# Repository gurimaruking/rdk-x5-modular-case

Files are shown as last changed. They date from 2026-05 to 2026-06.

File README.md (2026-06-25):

# RDK X5 Modular Case

> **The first open-source 3D-printable case for D-Robotics RDK X5 8GB.**
> Fully parametric OpenSCAD source. One base, four swappable lids.
> Licensed under **CC BY 4.0**.

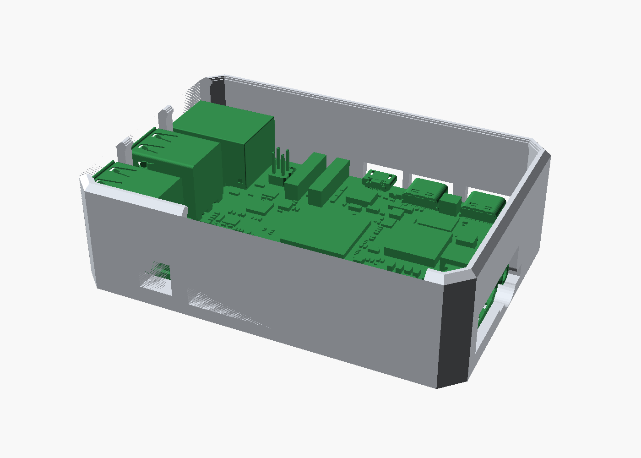
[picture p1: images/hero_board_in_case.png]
RDK X5 seated in the base — every port lined up


<p align="center">
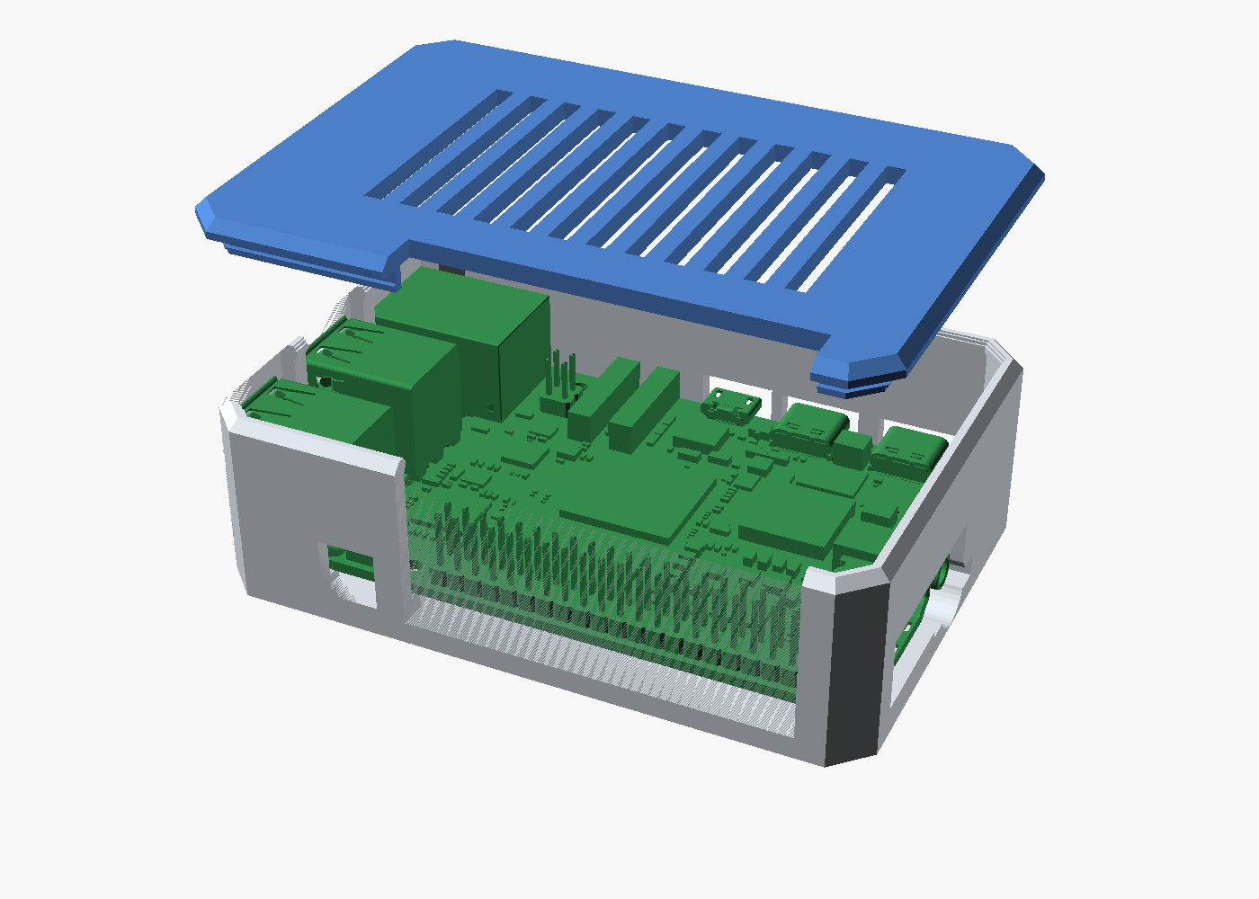
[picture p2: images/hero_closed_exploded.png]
Closed lid snapping on
  
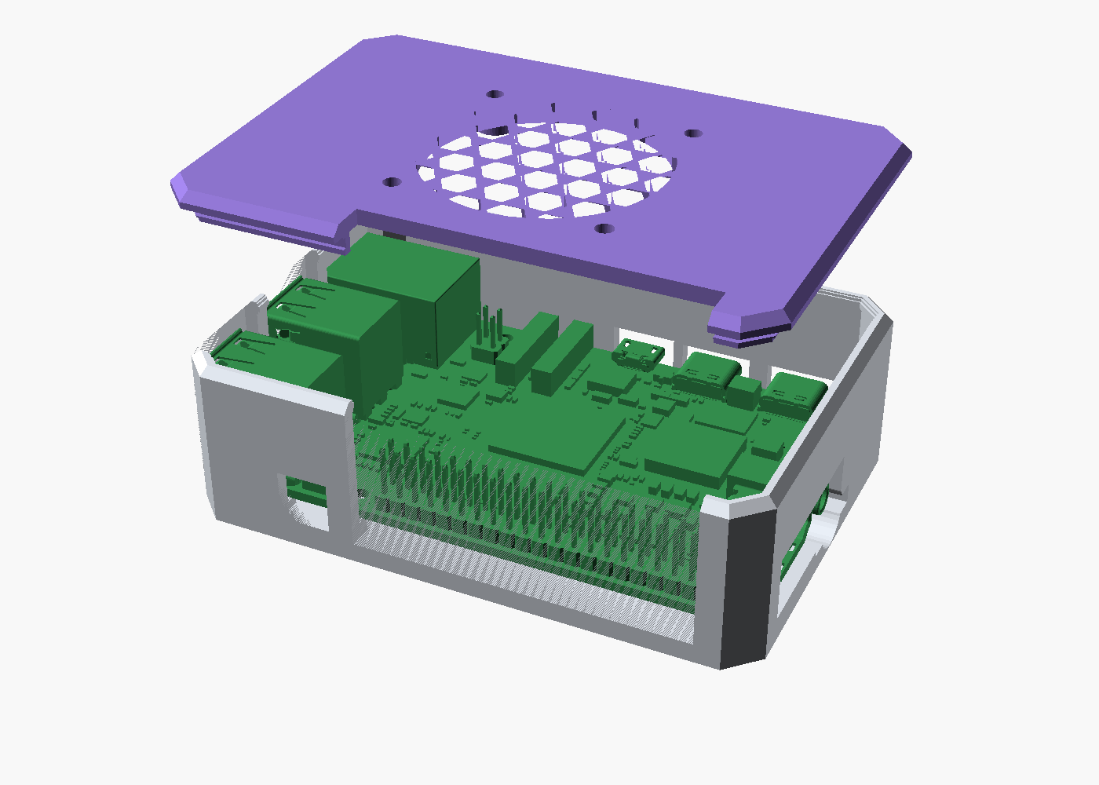
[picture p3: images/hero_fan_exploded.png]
Fan lid snapping on
  
</p>

> Snap-on lids over a board held by an outer clamp — no PCB-side screws.

## Why this exists

As of May 2026, RDK X5 has **no community 3D-printable case** on Printables,
Thingiverse, Cults3D, or English-language MakerWorld. The official metal/acrylic
cases from Yahboom, Waveshare, and DFRobot are heavy and don't fit inside
robot bodies. This repo fills that gap with a community-first, remix-friendly
modular design.

Originally built as a byproduct of [Project Korosuke (コロ助)](https://github.com/Robostadion/corosuke-robot),
an animatronic robot competing in the **D-Robotics Robotics Dream Keeper Challenge**.

## One base, four lids

| Lid | Preview | STL | Use case |
|-----|---|-----|---|
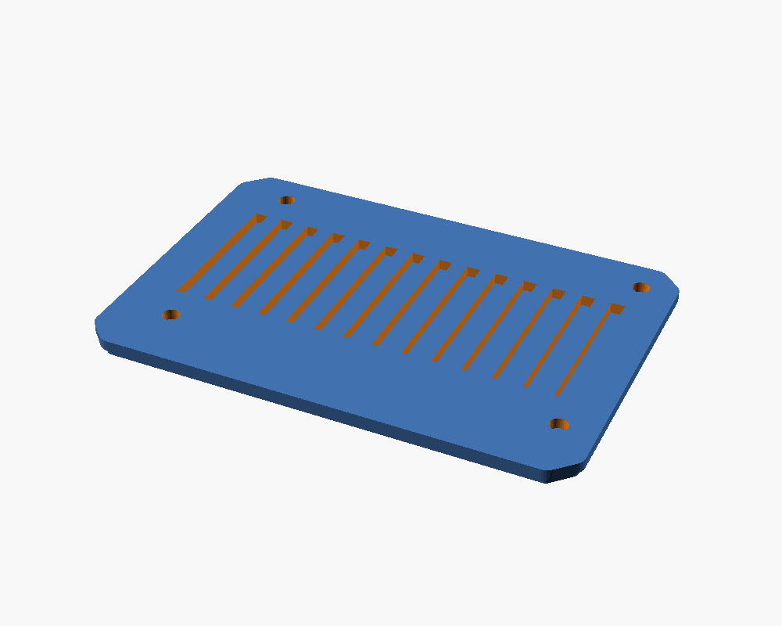
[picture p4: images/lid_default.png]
| **Default** (closed, cooling slits) |  | [`lid_default.stl`](stl/lid_default.stl) | Everyday use, dust protection, mild cooling |
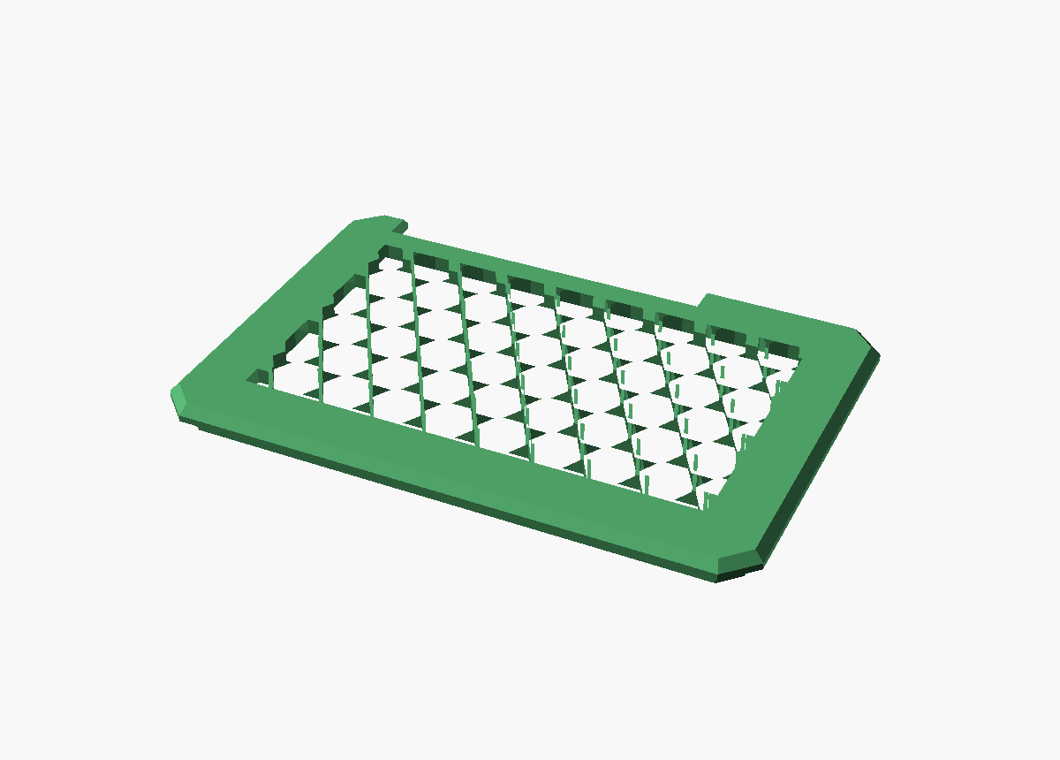
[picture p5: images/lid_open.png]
| **Open** (honeycomb vent) |  | [`lid_open.stl`](stl/lid_open.stl) | Maker projects, full heatsink exposure, max airflow |
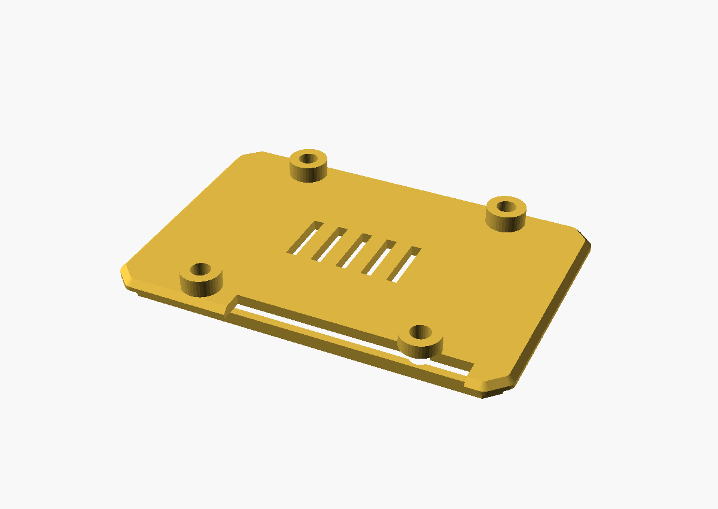
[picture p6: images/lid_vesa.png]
| **VESA Mount** (50×50 M4) |  | [`lid_vesa.stl`](stl/lid_vesa.stl) | 50 mm 4-hole bracket mount (board is too small for full VESA-75) |
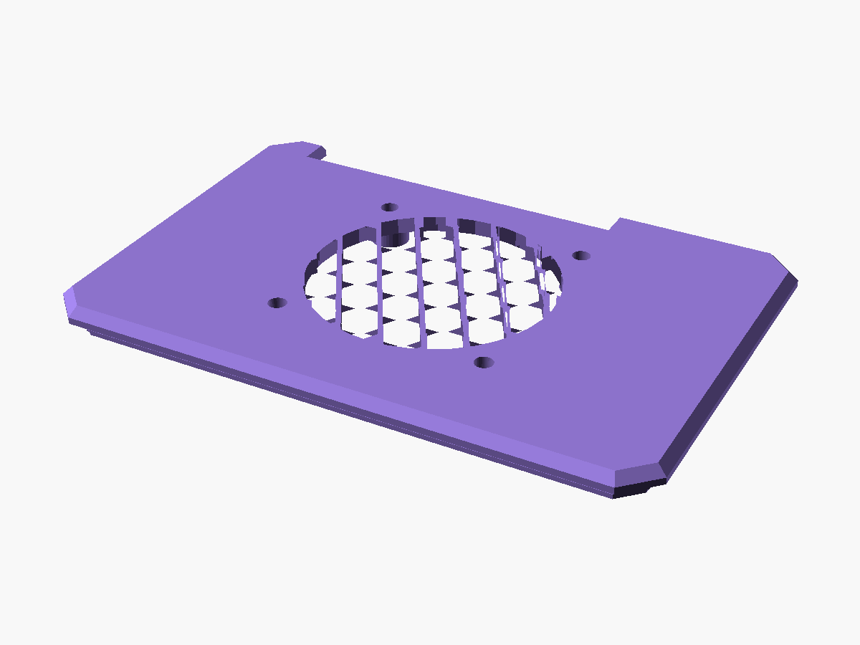
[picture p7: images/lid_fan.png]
| **Fan** (40 mm fan mount) |  | [`lid_fan.stl`](stl/lid_fan.stl) | Active cooling — mount a 40 mm fan (e.g. 4010) over a honeycomb intake grille |

Common base: [`case_base.stl`](stl/case_base.stl) — works with all four lids.

### Powering the fan

The **Fan lid** takes a standard **40 × 40 × 10 mm (4010) 5 V fan**, held by
**4× M3 × 15 mm screws** on the 32 mm pattern — that length is a perfect fit
through the fan into the lid bosses. The center honeycomb doubles as a finger
guard and intake grille; the fan blows down onto the heatsink.

> ⚠️ The RDK X5's onboard fan header (**J15**) is a JST-SH **1.0 mm 2-pin** and
> is too small for most hobby-fan plugs. The simplest reliable hookup is the
> **40-pin GPIO header**: fan **+ (red) → pin 4 (5V)**, **− (black) → pin 6 (GND)**.
> This runs the fan full-speed whenever the board is powered.
>
> **Measured cooling (assembled, lid on):** idle **66 °C passive → 41 °C** with the
> 4010 fan ducted through the honeycomb — a **−25 °C** drop, plenty of headroom for
> running YOLO on the BPU.

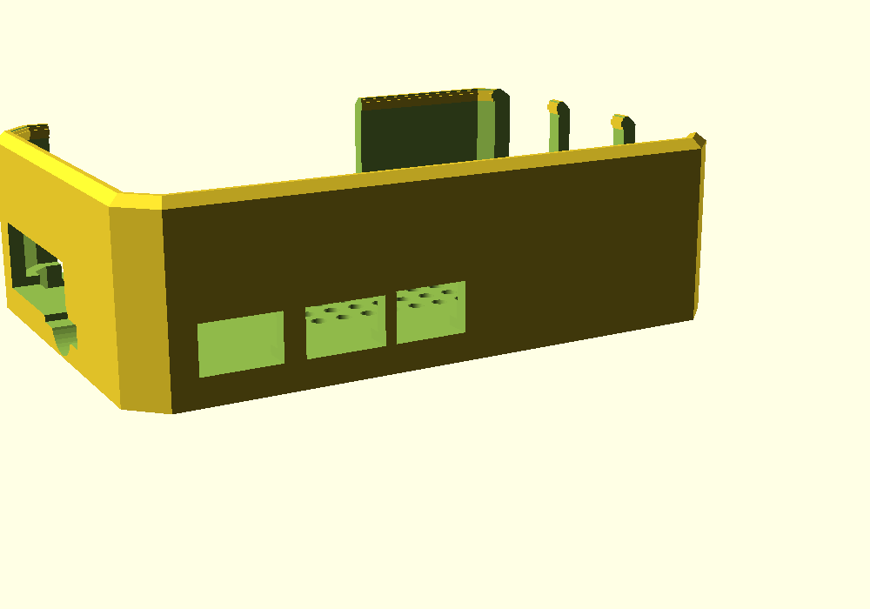
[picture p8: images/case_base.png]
Base


## Specifications

| Item | Value |
|---|---|
| Compatible board | D-Robotics RDK X5 8GB (Part No. DROBOTICS-RDK-X5-8GB-V10) |
| Reference source | Official D-Robotics V1P0 DXF & STEP (`reference/`) |
| Case footprint | ~89 × 60 × 24 mm |
| PCB retention | Outer clamp (no PCB-side screws — preserves stock heatsink holes) |
| Lid attachment | **Snap / press-fit — no screws** (tunable via `SNAP_CLEAR`) |
| Designed material | PLA / PETG (2.0 mm wall) |
| License | CC BY 4.0 |

## Build (STL from source)

Requires [OpenSCAD](https://openscad.org/) 2021.01 or newer.

```bash
# Render all parts in one go
openscad -o stl/case_base.stl   -D 'SHOW=11' rdk_x5_case.scad
openscad -o stl/lid_default.stl -D 'SHOW=12' rdk_x5_case.scad
openscad -o stl/lid_open.stl    -D 'SHOW=13' rdk_x5_case.scad
openscad -o stl/lid_vesa.stl    -D 'SHOW=14' rdk_x5_case.scad
openscad -o stl/lid_fan.stl     -D 'SHOW=25' rdk_x5_case.scad
# (SHOW=11–14,25 = print-ready, flat on Z=0. SHOW=1–4,15 = design orientation.)
```

Or run `./build_all.sh` (Linux/macOS) / `build_all.ps1` (Windows).

## Print settings (suggested starting point)

| Parameter | Value |
|---|---|
| Layer height | 0.20 mm |
| Walls / Perimeters | 3 |
| Top/Bottom layers | 4 / 4 |
| Infill | 20 % (gyroid) |
| Supports | **None needed** — designed support-free |
| Brim | Optional (5 mm) for warping-prone filaments |
| Filament | PLA, PETG, or PC-blend; ABS optional |

## Customization

Open `rdk_x5_case.scad` and edit the `// PARAMETERS` block. Useful knobs:

| Variable | Default | When to change |
|---|---|---|
| `GAP` | 1.0 mm | Per-side PCB clearance. Lower (0.8) for a snug board, raise if it binds. Printers with elephant's foot may need more — or enable foot compensation in the slicer |
| `SNAP_CLEAR` | 0.05 mm | Lid lip press-fit. Lower = tighter lid; negative = interference |
| `SNAP_BEAD` | 0.45 mm | Snap ridge/groove engagement depth. Raise for a firmer click, lower if the lid won't close |
| `TOP_CLEAR` | 20 mm | Increase if using a tall heatsink + fan |
| `WALL` | 2.2 mm | Drop to 1.6 for ABS, raise to 3.0 for TPU |
| `VESA` | 50 (50×50 M4) | Max that fits on the 56 mm-deep lid; an assert guards against overhang |

## Roadmap

- [x] Default Lid — closed + cooling slits
- [x] Open Lid — frame with X-cross ribs
- [x] VESA Mount Lid — 50×50 M4 pattern (bosses fully supported on the lid)
- [x] Fan Lid — 40 mm fan mount (32 mm M3 pattern) with honeycomb intake grille
- [x] Accurate port cutouts — every connector position extracted from the
      official STEP model and verified against the real board mesh
      (USB-A ×2, RJ45, HDMI, audio, USB-C ×2, UART debug, 40-pin GPIO, microSD, fan).
      See [connector_map.md](connector_map.md) and
      `images/board_fit_verification.png`.
- [ ] Camera Lid — MIPI CSI cable pass-through (planned)
- [ ] DIN-rail Lid — industrial mount (community request welcome)
- [ ] Print validation on real hardware (PLA / PETG)
- [ ] Thermal validation under load

## Disclaimer

This is an unofficial community design. Not affiliated with or endorsed by
D-Robotics. PCB outline geometry is derived from D-Robotics' publicly
released DXF/STEP mechanical drawings (`reference/`); those original CAD
files remain the property of D-Robotics and are included for design
verification only.

## License

**CC BY 4.0** — see [LICENSE](LICENSE). You may share and adapt freely,
including commercially, as long as you give credit.

## Acknowledgments

- **D-Robotics** for publishing the mechanical reference files openly.
- **Lisa Li** and the Robotics Dream Keeper Challenge team for the warm welcome.
- The Korosuke / コロ助 character from *Kiteretsu Daihyakka* — the spark
  for this entire project.

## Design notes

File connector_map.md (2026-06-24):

# RDK X5 コネクタ実測マップ(公式STEPから抽出)

> 抽出元: RDK_X5_LPDDR4_4266MHz_V1P0_pcb.stp(FreeCADでbbox抽出)
> 座標系: 基板左下を原点、X 0..85 / Y 0..56 mm(DXF外形と一致)
> Z: 基板上面を概ね0として、コネクタの高さ範囲。基板全体のZ範囲 -4.49..16.18

## 各エッジのポート配置

### 右エッジ (X+ = 85側) — 背の高いI/O
| ポート | Y範囲 | Z範囲(高さ) | 備考 |
|---|---|---|---|
| RJ45(LAN) | 2.1 – 18.3 | -3.7 – 13.5 | 背高17mm |
| USB-Aスタック1 | 22.0 – 36.5 | -1.9 – 16.2 | 2段USB、背高18mm |
| USB-Aスタック2 | 39.9 – 54.4 | -1.9 – 16.2 | 2段USB、背高18mm |

### 左エッジ (X- = 0側)
| ポート | Y範囲 | Z範囲 | 備考 |
|---|---|---|---|
| HDMI | 34.0 – 49.0 | -2.3 – 6.1 | フルサイズHDMI |
| 3.5mmオーディオ(PJ-327) | 24.5 – 30.8 | -2.8 – 4.8 | ヘッドホンジャック |

### 前エッジ (Y- = 0側)
| ポート | X範囲 | Z範囲 | 備考 |
|---|---|---|---|
| USB Type-C #1(電源) | 6.7 – 15.7 | -0.8 – 3.2 | 5V/5A電源入力 |
| USB Type-C #2(データ) | 21.3 – 30.3 | -0.8 – 3.2 | デバッグ/データ |
| **UART (Micro-USB, Molex 1050170001)** | 34.7 – 42.2 | 0 – 2.7 | デバッグシリアル。基板にCH340内蔵。Micro-USBケーブル直挿し115200。**v5.1で誤って"MIPI DSI"と記載していたが実体はMicro-USB**(silk"UART"はX42.9に右隣印字) |
| MIPI CSI カメラ FPC ×2(縦型) | X47/53, Y0–16.7 | 上面 | 基板上面、リボンは上 |

### 後エッジ (Y+ = 56側)
| ポート | X範囲 | Z範囲 | 備考 |
|---|---|---|---|
| **40ピンGPIOヘッダ** | 7.1 – 57.9 | -3.0 – 10.6 | 長さ51mm、背高。リボン上/後方向 |
| ファン/電源 JST | 64.7 – 70.0 | 0 – 4.4 | 小型JST |

### 底面 (Z-)
| ポート | X範囲 | Y範囲 | Z範囲 | 備考 |
|---|---|---|---|---|
| microSDスロット | 2.0 – 13.3 | 20.5 – 31.9 | -3.3 – -1.4 | 基板裏。カードは左(-X)へ抜く |

## 設計への反映ルール
- 右壁: RJ45 + USB×2 の大開口(背が高いので壁上端まで開ける=オープントップ)
- 左壁: HDMI + オーディオの開口
- 前壁: USB-C×2 の開口(電源は必須アクセス)
- 後壁: GPIO用の幅広スロット(リボンケーブルが後方へ抜ける)+ ファンJST小開口
- 底/左下: microSDカード抜き差し用スロット
- FPC(カメラ/ディスプレイ)は内部高さ確保のみ。リボンはリッド側で処理(camera lid)
- マウント: 4穴は右端集中(ヒートシンク用)なので使わず、外周クランプ保持

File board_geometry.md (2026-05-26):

# RDK X5 基板寸法サマリ(設計用)

公式DXF(`RDK_X5_LPDDR4_4266MHz_V1P0_top_dxf.dxf`)解析で確定した寸法情報。
原点は基板の左下コーナー(chamferなしの仮想角)とする。座標単位はmm。

## 基板外形

- **サイズ: 85.0 × 56.0 mm**
- **4隅: C3 chamfer**(直線3mmカット、円弧フィレットではない)
- **厚さ: 約20mm**(ヒートシンク・コネクタ含む全体高、CNX Software計測)
- **PCB厚: 約1.6mm**(標準FR4想定、要実機確認)

### 外形ポリライン頂点(時計回り)

```
(3,56) → (82,56) → (85,53) → (85,3) → (82,0) → (3,0) → (0,3) → (0,53) → (3,56)
```

### ASCII図

```
Y
56  +---+--------------------------+
    |  /                            \
53  | /                              \
    |/                                |
    |                                 |
    |     RDK X5 PCB                  |
    |     85 x 56 mm                  |
    |                                 |
    |\                                |
 3  | \                              /
    |  \                            /
 0  +---+--------------------------+
    0   3                       82 85   X
```

## マウント穴(top DXF解析結果)

> 注意: **4隅マウントではない**。穴は基板右端(x=74〜78)に偏在。
> 用途は「ヒートシンク取付」「専用ブラケット」と推定。汎用M3 4点支持には使えない。

| ID | 直径 | 中心座標 (x, y) | 推定用途 |
|----|---|---|---|
| H1 | 3.2mm (M3) | (77.12, 4.48) | ヒートシンク or ブラケット |
| H2 | 3.2mm (M3) | (77.12, 15.91) | ヒートシンク or ブラケット |
| H3 | 2.46mm (M2.5) | (74.07, 2.32) | サブマウント |
| H4 | 2.46mm (M2.5) | (74.07, 18.07) | サブマウント |

### その他検出されたCIRCLE

- dia 3.08mm × 8個(基板右上 x=72.6/78.28、y=22.69/35.83/40.65/53.79)
  → 規則配列、おそらく**コネクタの大型スルーホール**(2.54mmピッチではない)
- dia 4.70mm × 4個 → 大型コンポーネント(電源コネクタ等)のリード穴と推定

## 動作仕様

| 項目 | 値 | 出典 |
|---|---|---|
| 動作温度 | -20°C ~ 60°C | CNX Software |
| 電源 | USB Type-C 5V/5A | CNX Software |
| SoC TDP | 公表なし(発熱多めとの中華レビューあり) | コミュニティ |

## コネクタ配置(要追加調査)

公式hardware docsには文章説明あるが、座標情報は別途整理が必要。
実機到着済みのため、**ノギスでの実測 + 公式STEPファイル(`*.stp`)をFreeCADで開いて確認**するのが確実。

主要コネクタ(推定):
- USB Type-C(電源) × 1
- USB 3.0/2.0 × 複数
- HDMI × 1
- Gigabit Ethernet × 1
- 40ピン GPIO ヘッダ
- MIPI CSI(カメラ) × 2
- MIPI DSI(ディスプレイ) × 1
- 3.5mm オーディオ
- microSD スロット
- ファンコネクタ
- スピーカーコネクタ
- マイクボードコネクタ

## ケース設計への含意

**ネジ穴4点支持が使えない**ことから、汎用ケース設計は次の選択肢になる:

1. **スナップフィット式クラムシェル** — 全周をクランプで挟む。ネジ不要。組立簡単・印刷も楽
2. **スライドイン式トレー + リッド** — 基板を横からスライド挿入、リッドで蓋
3. **既存の2本M3穴 + 縁サポートのハイブリッド** — 既存穴に頼りつつ、対角は外周クランプで支える
4. **基板の4隅外側に外部フレーム** — 基板を抱きかかえる形のフレームで保持。基板側にネジを使わない

これらの方針は次の設計セッションでユーザーと決定する。

## 残課題

- [x] Bottom DXF も解析してネジ穴漏れがないか確認 → **同じ4穴のみ確認、漏れなし**
- [ ] STEP ファイルから3Dでコネクタ位置を測定(FreeCAD)
- [ ] 実機を確認してコネクタ位置・基板厚を実測
- [ ] 発熱パターン把握(SoC直上の温度分布)
- [ ] 純正ヒートシンクが付属しているか、その寸法

## 結論: 設計戦略

公式ネジ穴 4 点はすべて基板右下に固まっており、**ケース固定には使わない方が汎用性が高い**(純正ヒートシンク取付用を残しておく方がユーザーフレンドリー)。

→ 汎用ケースは **基板外周をクランプ/スナップフィット** で保持する設計が筋。

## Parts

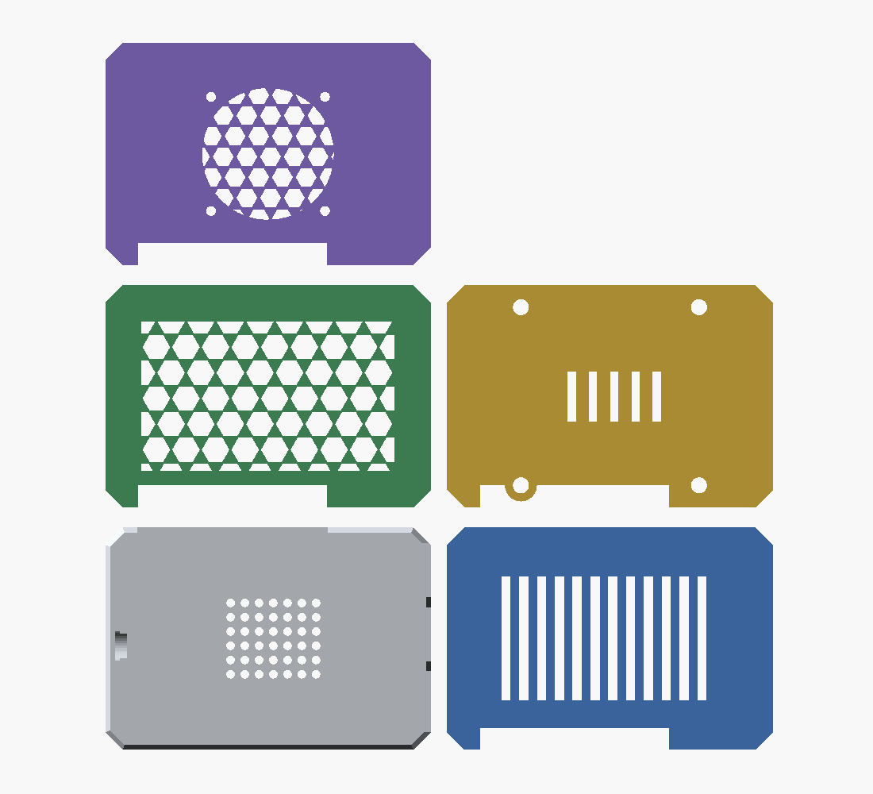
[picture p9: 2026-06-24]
images/all_parts_plate.png

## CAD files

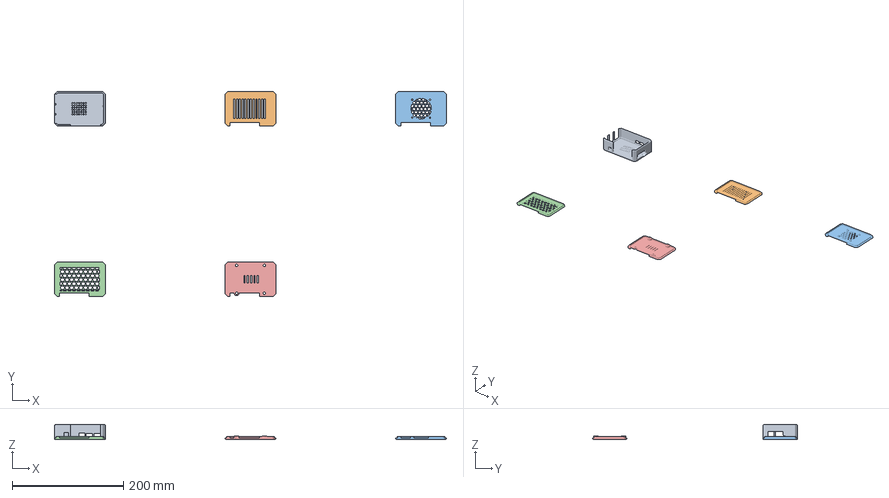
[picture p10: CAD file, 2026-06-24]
stl/rdk_x5_case.3mf
705.8 x 369.6 x 27.1 mm
case_base.stl
lid_default.stl
lid_fan.stl
lid_open.stl
lid_vesa.stl

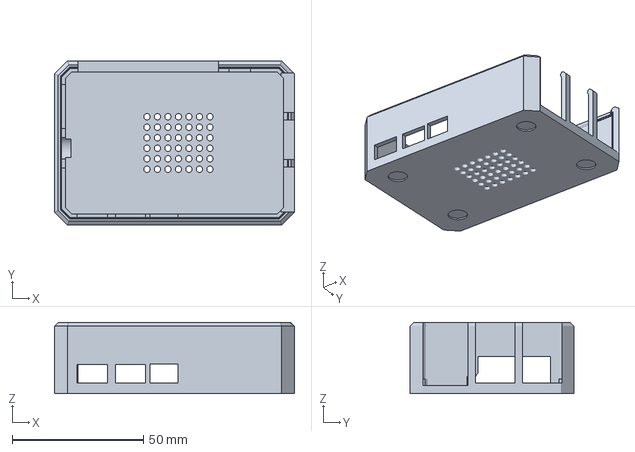
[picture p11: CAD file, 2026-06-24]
stl/case_base.3mf
91.4 x 62.4 x 27.1 mm

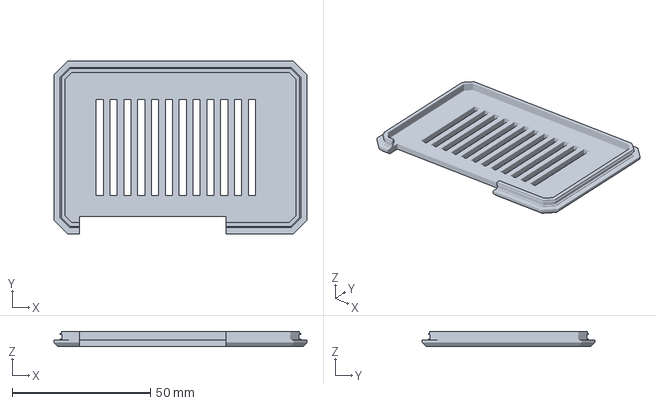
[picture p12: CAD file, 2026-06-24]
stl/lid_default.3mf
91.4 x 62.4 x 5.40 mm

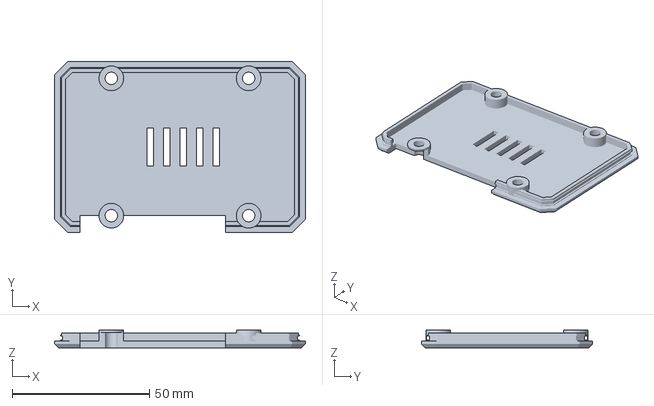
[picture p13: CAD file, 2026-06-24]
stl/lid_vesa.3mf
91.4 x 62.4 x 6.40 mm

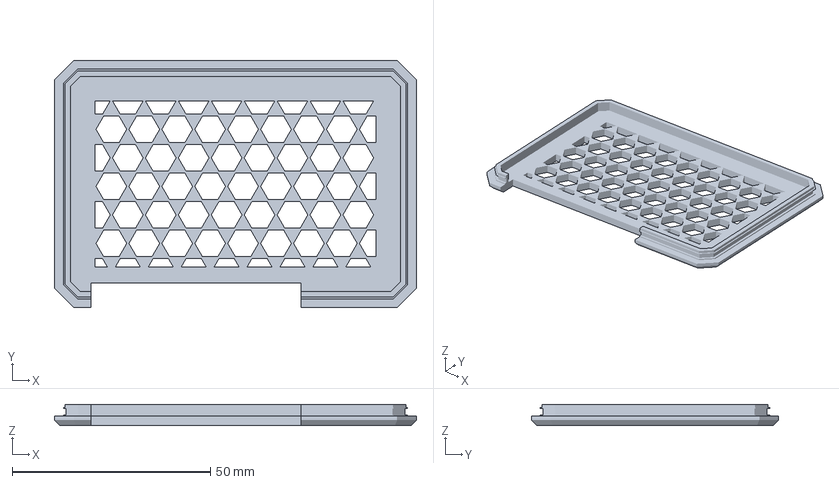
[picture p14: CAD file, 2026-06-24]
stl/lid_open.3mf
91.4 x 62.4 x 5.40 mm

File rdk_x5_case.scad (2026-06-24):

/*
 * RDK X5 Modular Case v2 — accurate, port-correct, simple functional design
 *
 * Connector positions extracted from the official STEP
 * (RDK_X5_LPDDR4_4266MHz_V1P0_pcb.stp) via FreeCAD bbox analysis.
 * See connector_map.md. Verified by overlaying the real board mesh.
 *
 * Frame: PCB bottom-left = origin. X 0..85, Y 0..56. Z=0 at floor bottom.
 * One base + three lids (closed / open / VESA). Aesthetic: chamfered top
 * edges + cooling slits. No screws — friction lip + optional M3 in corners.
 *
 * Author: Kazuki Murata / Robostadion     License: CC BY 4.0
 */

// ---------- core dimensions ----------
PCB_W=85; PCB_D=56; PCB_CH=3; PCB_T=1.6;
WALL=2.2; FLOOR=2.0; GAP=1.00;   // v5: 0.80→1.00 (実機印刷で基板がまだギチギチ・底まで座らない→さらに広げた)
BOTTOM_CLEAR=3.5;          // under PCB (pins, microSD)
TOP_CLEAR=20.0;            // above PCB top (tall USB ~16.5 + headroom for lip)
LEDGE=2.0;                 // perimeter ledge PCB rests on
LID_TOP=2.4;               // lid plate thickness
LIP_DEPTH=3.0;             // lid locating lip depth (in the clear zone)
LIP_W=1.8;
CHAM=1.4;                  // top outer edge chamfer
// --- press-fit (no screws) ---
//  per-side clearance between lid lip and base cavity wall.
//  0.10 = snug press fit (push to close, holds by friction).
//  v4: スリップフィット(0.10)に戻し、保持は下記のsnap bead/grooveで行う
//  → 蓋はスッと入って、最後にパチッと噛んで外れにくい
SNAP_CLEAR=0.02;   // v5.1: 0.05→0.02 (蓋がまだ気持ち緩い→さらに密着)
LEAD_IN=0.8;               // lip bottom lead-in chamfer height (eases insertion)
// --- snap-fit ring (base=凸リッジ / lid=凹溝, 一周) ---
//  ベース側キャビティ壁に一周のリッジ、蓋リップ外面に一周の溝。押し込むと
//  リップが少したわんでリッジを乗り越え、溝にカチッと落ちて保持する。
//  きつくて閉まらない→SNAP_BEAD下げる / 緩い→上げる
SNAP_BEAD=0.55;            // v5.1: 0.45→0.55 (まだ緩いのでカチッと更に強く). ridge protrusion = groove engagement depth

PCB_BOT=FLOOR+BOTTOM_CLEAR;
PCB_TOP=PCB_BOT+PCB_T;
WALL_TOP=PCB_TOP+TOP_CLEAR;
// NOTE: SNAP_Z depends on WALL_TOP, so it MUST be defined AFTER it. Defining it
// earlier left WALL_TOP undefined at that point -> SNAP_Z=undef -> snap_bead /
// snap_groove silently rendered empty (a likely cause of the loose-lid feel).
SNAP_Z=WALL_TOP-1.6;       // engagement height (within the lip zone)

$fn = $preview ? 40 : 110;

// ---------- PCB outline (chamfered) ----------
module pcb_poly(){
    polygon([[PCB_CH,0],[PCB_W-PCB_CH,0],[PCB_W,PCB_CH],
             [PCB_W,PCB_D-PCB_CH],[PCB_W-PCB_CH,PCB_D],
             [PCB_CH,PCB_D],[0,PCB_D-PCB_CH],[0,PCB_CH]]);
}
// NOTE: use offset(delta=) not offset(r=).  offset(r=negative) returns empty
// on this polygon in OpenSCAD 0.21, which silently broke every inward offset
// (lid lip ring, under-PCB recess, open-lid window). delta offsets reliably.
module pcb_off(d){ offset(delta=d) pcb_poly(); }
OUT = GAP+WALL;   // outer offset

// ============================================================
// PORT MAP  [edge,a0,a1,zmin,zmax,openTop,"label"]
//  edge R(X+) L(X-) F(Y-) B(Y+); a along edge; z rel PCB top
// ============================================================
PORTS=[
 // right edge: spans tightened to the real connector bbox so the dividers
 // between RJ45 / USB1 / USB2 stay ~2 mm thick (conns are only ~3.4 mm apart)
 // v3: right openings tightened to the connectors so USB/RJ45 dividers reach ~2.8 mm
 ["R", 2.0,18.6,-4,14.0,1,"RJ45 LAN"],
 ["R",21.9,36.6,-3,16.5,1,"USB-A stack1"],
 ["R",39.8,54.5,-3,16.5,1,"USB-A stack2"],
 // v3: HDMI+Audio MERGED into one opening (the 1.2 mm wall between them was too
 // fragile to print). Covers Y23.5..50, tall enough for HDMI.
 ["L",23.0,50.0,-3, 6.8,0,"HDMI + Audio"],
 ["F", 5.7,16.7,-3, 3.7,0,"USB-C power"],
 ["F",20.3,31.3,-3, 3.7,0,"USB-C data"],
 // v5.2: UART debug = a Micro-USB receptacle (Molex 1050170001, on-board CH340
 // USB-serial). Measured from the board mesh as the 7.5 mm-wide connector that
 // protrudes past the front edge at X 34.71–42.21 (the DXF silk "UART" text at
 // X≈42.9 is printed to the RIGHT of the connector, which misled v5.1). Plug a
 // Micro-USB cable straight in (115200 8N1) for the boot/kernel console.
 ["F",33.4,43.5,-3, 4.0,0,"UART (Micro-USB)"],
 ["B", 6.0,59.0,-4,11.5,1,"40pin GPIO"],
 ["B",63.5,71.2,-3, 4.9,0,"Fan/PWR JST"],
];
CLR=0.25;  // per-side opening clearance (tighter -> thicker port dividers)

module port_cut(p){
    e=p[0]; a0=p[1]-CLR; a1=p[2]+CLR;
    z0=PCB_TOP+p[3]; z1 = p[5]==1 ? WALL_TOP+1 : PCB_TOP+p[4]+CLR;
    thru=WALL+GAP+2;
    if(e=="R") translate([PCB_W-2,a0,z0]) cube([thru,a1-a0,z1-z0]);
    else if(e=="L") translate([-(WALL+GAP)-1,a0,z0]) cube([thru,a1-a0,z1-z0]);
    else if(e=="F") translate([a0,-(WALL+GAP)-1,z0]) cube([a1-a0,thru,z1-z0]);
    else if(e=="B") translate([a0,PCB_D-2,z0]) cube([a1-a0,thru,z1-z0]);
}
module microsd_slot(){
    // v4: 拡大(取り出しやすく)+ 指がかりの半円スカラップ
    z0=PCB_TOP-4.0; z1=PCB_TOP-0.6;
    translate([-(WALL+GAP)-1,18.5,z0]) cube([WALL+GAP+4,15.0,z1-z0]);
    // finger scallop: 壁の縁に半円の切り欠き(爪でカードを摘まめる)
    translate([-(WALL+GAP)-1,26.0,z0+(z1-z0)/2]) rotate([0,90,0])
        cylinder(d=9, h=WALL+GAP+4, $fn=40);
}
module floor_vents(){ for(i=[0:6],j=[0:5]) translate([32+i*4,18+j*4,-1]) cylinder(d=2.4,h=FLOOR+2); }
module foot_recess(){ for(p=[[9,8],[76,8],[9,48],[76,48]]) translate([p[0],p[1],-0.1]) cylinder(d=8,h=0.8); }

// snap ridge on the base cavity wall (一周凸). Triangular-ish for easy ride-over.
// Clipped at the port openings (tall USB/GPIO notches have no wall to back it).
module snap_bead(){
    difference(){
        union(){
            translate([0,0,SNAP_Z-0.5]) linear_extrude(0.5)
                difference(){ pcb_off(GAP); pcb_off(GAP-SNAP_BEAD*0.5); }   // lower ramp
            translate([0,0,SNAP_Z]) linear_extrude(0.9)
                difference(){ pcb_off(GAP); pcb_off(GAP-SNAP_BEAD); }       // full ridge
            translate([0,0,SNAP_Z+0.9]) linear_extrude(0.45)
                difference(){ pcb_off(GAP); pcb_off(GAP-SNAP_BEAD*0.5); }   // upper ramp
        }
        for(p=PORTS) port_cut(p);   // no bead across the open-top port notches
    }
}
// matching groove cut into the lid lip outer face (一周凹)
module snap_groove(){
    translate([0,0,SNAP_Z-0.35]) linear_extrude(1.6)
        difference(){ pcb_off(GAP-SNAP_CLEAR+0.3); pcb_off(GAP-SNAP_CLEAR-SNAP_BEAD-0.15); }
}

// chamfered top rim helper (outer top edge bevel)
module top_chamfer(offv){
    hull(){
        translate([0,0,WALL_TOP-CHAM]) linear_extrude(0.01) pcb_off(offv);
        translate([0,0,WALL_TOP-0.01]) linear_extrude(0.01) pcb_off(offv-CHAM);
    }
}

// ============================================================
// BASE
// ============================================================
module case_base(){
    union(){
        difference(){
            union(){
                linear_extrude(WALL_TOP-CHAM) pcb_off(OUT);
                top_chamfer(OUT);
            }
            // cavity for PCB + components
            translate([0,0,PCB_BOT]) linear_extrude(WALL_TOP) pcb_off(GAP);
            // under-PCB recess (PCB rests on LEDGE ring)
            translate([0,0,FLOOR]) linear_extrude(BOTTOM_CLEAR+0.01) pcb_off(GAP-LEDGE);
            // accurate ports
            for(p=PORTS) port_cut(p);
            microsd_slot();
            floor_vents();
            foot_recess();
        }
        // snap ridge inside the cavity (engages the lid groove). Clipped so it
        // doesn't grow into the port openings region too aggressively.
        snap_bead();
    }
}

// ============================================================
// LID common: top plate + locating lip + top chamfer
// ============================================================
module lid_plate_2d(){ pcb_off(OUT); }
module lid_lip(){
    // press-fit lip in the clear zone (above all connectors).
    // IMPORTANT: stays a RING at every level. (Never hull() a ring — the convex
    // hull of an annulus is a solid disk, which would plug the open lid.)
    lo = GAP - SNAP_CLEAR;        // outer offset -> press fit against cavity (pcb_off(GAP))
    li = lo - LIP_W;             // inner offset
    translate([0,0,WALL_TOP-LIP_DEPTH]){
        // lead-in: bottom ring inset on the OUTER face only (eases insertion)
        linear_extrude(LEAD_IN) difference(){ pcb_off(lo-0.4); pcb_off(li); }
        // main grip ring
        translate([0,0,LEAD_IN])
            linear_extrude(LIP_DEPTH-LEAD_IN) difference(){ pcb_off(lo); pcb_off(li); }
    }
}
module lid_chamfer_top(){
    // chamfer the lid's own top outer edge
    z=WALL_TOP+LID_TOP;
    hull(){
        translate([0,0,z-CHAM]) linear_extrude(0.01) pcb_off(OUT);
        translate([0,0,z-0.01]) linear_extrude(0.01) pcb_off(OUT-CHAM);
    }
}
module lid_body(){
    // plate from WALL_TOP up
    union(){
        translate([0,0,WALL_TOP]) linear_extrude(LID_TOP-CHAM) lid_plate_2d();
        lid_chamfer_top();
        lid_lip();
    }
}
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

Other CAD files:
reference/RDK_X5_LPDDR4_4266MHz_V1P0_top_dxf.dxf
reference/RDK_X5_LPDDR4_4266MHz_V1P0_bottom_dxf.dxf
stl/lid_fan.3mf
stl/case_base.stl
stl/lid_default.stl
stl/lid_fan.stl
stl/lid_open.stl
stl/lid_vesa.stl

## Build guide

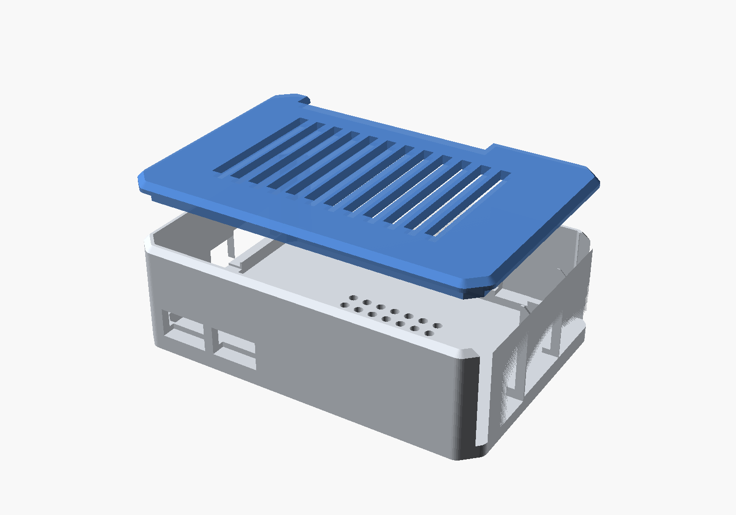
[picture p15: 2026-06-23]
images/assembly_preview.png

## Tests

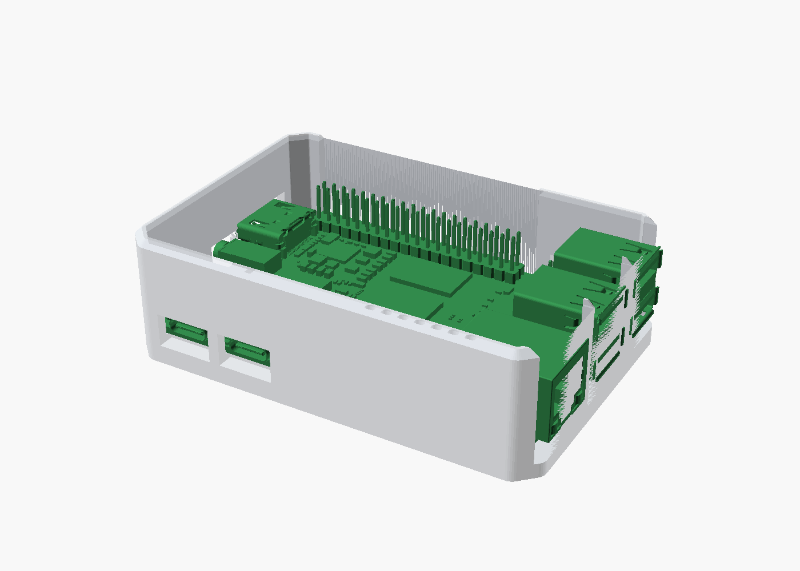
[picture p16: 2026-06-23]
images/board_fit_verification.png

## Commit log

2026-05-26 初回リリース: RDK X5用3タイプモジュラーケース (default/open/VESA)
    - 共通ベース + 3種類リッド(閉鎖型/オープン/VESA60マウント)
    - OpenSCADフルパラメトリック設計
    - STL 4ファイル + プレビュー画像 5枚同梱
    - 公式D-Robotics STEP/DXFをreference/に保管
    - ライセンス: CC BY 4.0
    [RDK_X5_LPDDR4_4266MHz_V1P0_bottom_dxf.dxf, RDK_X5_LPDDR4_4266MHz_V1P0_top_dxf.dxf, case_base.stl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]
2026-06-23 v2: 公式STEPから実測した正確なポートカットアウトに刷新
    - 全コネクタ位置(USB-A×2/RJ45/HDMI/オーディオ/USB-C×2/40pin GPIO/microSD/ファン)を
    公式STEPからFreeCADで抽出、実物基板メッシュと重ねて整合を検証
    - v1の仮穴2個から、全ポート精密カットアウトへ全面再設計
    - 外周面取り+冷却スリット+床ベント+ゴム足座ぐり+GPIOリボン逃げ(シンプル機能美)
    - STL/3MF全4パーツ再生成、connector_map.md と検証画像を追加
    [case_base.3mf, case_base.stl, lid_default.3mf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]
2026-06-23 fix: VESAリッドのボス浮き修正(60→50mm、基板に完全に載るパターンへ)
    - 基板奥行56mmに対しVESA60×60は前後ボスがリッド縁からはみ出して浮いていた
    - 50×50 M4パターンに変更し全ボスを天板上に支持
    - はみ出しを検出するassertガードを追加(再発防止)
    - 中央スリットをボスを避けて配置、READMEの記述を50×50に更新
    [lid_vesa.3mf, lid_vesa.stl]
2026-06-23 fix: 右側ポート間の仕切りを太く(USB/RJ45開口をタイト化)
    - RJ45/USB1/USB2の開口が広すぎて仕切りが0.2〜0.5mmと細かった
    - 開口スパンを実コネクタbboxにタイト化、CLRを0.6→0.3に
    - 仕切り厚 RJ45-USB1=2.3mm / USB1-USB2=2.0mm に改善
    - 開口はコネクタに対し約0.6〜0.7mmマージンで挿入も確保
    [case_base.3mf, case_base.stl, rdk_x5_case.scad]
2026-06-23 feat: フタを圧入プレスフィット化(ネジ不要でパチっと保持)
    - リップのクリアランスを0.3→0.1mmにタイト化し押し込みで摩擦保持
    - 挿入しやすいリードイン面取り(0.8mm)を追加
    - SNAP_CLEARパラメータで嵌合のきつ/緩を1行調整可能に
    - 3リッド全て再生成、READMEの固定方式を「press-fit/ネジ不要」に更新
    [lid_default.3mf, lid_default.stl, lid_open.3mf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]
2026-06-23 fix: オープンリッドが塞がるバグを修正(根本原因2件)
    - lid_lip が hull() でリングを凸包化し中央を塞ぐソリッド円盤を生成していた
    → 純粋なリング+段差リードインに修正(オープンリッドが正しく開通)
    - offset(r=負) が空を返す不具合 → offset(delta=) に変更
    (リップのリング/基板下クリアランスも正しく生成されるように)
    - 全4パーツ watertight 確認、赤床貫通テストでオープン開通を実証
    [case_base.3mf, case_base.stl, lid_default.3mf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]
2026-06-23 feat: オープンリッドをハニカム(六角)ベントに刷新+全パーツ検証
    - ダサいX字リブを廃し、ハニカム六角ベントへ(通気・剛性・見た目を改善)
    - 全4パーツ watertight 確認(case_base/lid_default/lid_open/lid_vesa)
    - 断面でフタ-ベースのプレスフィット嵌合を確認(リップが正しくキャビティに着座)
    - リップは純リング維持(hull禁止)、ポート位置はSTEP実測のまま
    [case_base.3mf, case_base.stl, lid_default.3mf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]
2026-06-23 feat: 全パーツを印刷向き(Z=0平置き)で書き出し+VESAボスを裏側化
    - 各STL/3MFを印刷姿勢で出力(ベース=床下、フタ=天面下)→Bambuの自動底面で斜めにならない
    - VESAボスをリッド裏側へ移動し、反転印刷でも全パーツがZ=0で平らに着座
    - 全4パーツ watertight + 最低Z=0 を機械確認
    [case_base.3mf, case_base.stl, lid_default.3mf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]
2026-06-24 fix(v3): 実機テストのフィット問題を反映
    - 基板がキチキチで入らない → GAP 0.45→0.70(クリアランス拡大)
    - HDMI↔オーディオ間の脆い仕切りを廃止し1開口に統合
    - USB/RJ45間の仕切りを~2.8mmに厚く(CLR 0.3→0.25, 開口をコネクタに密着)
    - フタがゆるゆる → SNAP_CLEAR 0.10→-0.10(0.1mm干渉のプレスフィット)
    - 全4パーツ Z=0平置き・watertight 確認
    [case_base.3mf, case_base.stl, lid_default.3mf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]
2026-06-24 feat(v4): snap-fit(凸リッジ+凹溝)追加・基板GAP拡大・SDスロット改善
    - ベース内壁に一周の凸リッジ、蓋リップに一周の凹溝 → 押し込むとパチッと噛んで保持
    (ポート開口部ではリッジを自動クリップ。SNAP_BEAD=0.35で調整可)
    - 蓋はスリップフィット(SNAP_CLEAR 0.10)に戻し、保持はsnapが担当
    - GAP 0.70→0.80(基板がまだ硬かった→さらに余裕)
    - microSDスロット拡大+指がかりスカラップ(取り出しやすく)
    - 全4パーツ watertight・Z=0平置き確認
    [case_base.3mf, case_base.stl, lid_default.3mf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]
2026-06-24 ファン蓋追加・スナップ嵌合バグ修正・プレートファイル再生成
    - lid_fan: 40mmファン(4010)マウント蓋を新規追加(32mm M3+ハニカム吸気グリル)
    - 修正: SNAP_ZがWALL_TOP定義前でundef→全蓋のスナップ溝/ベースのリッジが
    空出力されていた問題を解消(蓋が緩い主因)。定義順を是正し全パーツ再出力
    - rdk_x5_case.3mf(MakerWorld用 全パーツ1プレート)をFan蓋込みで作り直し
    - README: 蓋4種化、ファン給電手順(GPIO 5V/GND)と実測冷却-17℃を追記
    - 全パーツwatertight検証済
    [case_base.3mf, case_base.stl, lid_default.3mf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]
2026-06-24 v5: 基板クリアランス拡大・蓋タイト化・GPIO枠撤去・プレート別オブジェクト化
    - GAP 0.80→1.00: 実機印刷で基板がギチギチ・底まで座らなかった(エレファント
    フットで底が狭まる)ため側壁クリアランスを拡大
    - 蓋タイト化: SNAP_CLEAR 0.10→0.05(リップ密着)、SNAP_BEAD 0.35→0.45(カチッと強め)
    - GPIO逃げを位置決めリップ下端まで貫通させ、GPIO真上の無駄な枠バーを撤去
    (ベース側が開口で何も掴んでおらずリボンを塞ぐだけだった)
    - rdk_x5_case.3mf を「結合1メッシュ」→「5個の別オブジェクト」で再構築(trimesh)
    - README: GAP/SNAP_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
    [case_base.3mf, case_base.stl, lid_default.3mf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]
2026-06-24 rdk_x5_case.3mf を真の5プレートBambu版に差し替え
    - ユーザーがBambu Studio(02.07.01.62)で作成した5プレート構成
    - 各プレートに1パーツ: Base / lid_default / lid_fan / lid_open / lid_vesa
    - スライス済プロファイル+プレートサムネイル入り(MakerWorld向け)
    - ジオメトリはv5(GAP1.0・GPIO枠撤去)を確認済
    [rdk_x5_case.3mf]
2026-06-24 v5.1: UART開口を追加・蓋をさらにタイト化
    - UART debug開口を前壁に追加(公式DXFのsilk "UART" X≈42.9、USB-Cと同じ前エッジ、
    DSIとCSIの間)。実機印刷でこの開口が無く、デバッグシリアルが挿せなかった問題に対応。
    ベース+実機ボードメッシュ重ねでコネクタとの一致を確認済
    - 蓋タイト化: SNAP_BEAD 0.45→0.55、SNAP_CLEAR 0.05→0.02(まだ気持ち緩かったため)
    - README: ポート一覧にUART追記。全パーツwatertight検証済
    注: 5プレート版 rdk_x5_case.3mf はBambu Studio製のため未更新(v5.1ジオメトリで要再作成)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
    [case_base.3mf, case_base.stl, lid_default.3mf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]
2026-06-24 削除された画像(case_base.png/fit_section.png)を復元
    v5.1コミットに意図せず混入していた画像削除を戻す。case_base.pngはREADMEで参照。
2026-06-24 v5.2: UART開口を実コネクタ(Micro-USB)位置に修正
    実機ボードメッシュを再測定し、前エッジから飛び出すコネクタをクラスタリング。
    UARTデバッグは Micro-USB(Molex 1050170001 / CH340内蔵)で実位置 X34.7-42.2。
    v5.1はsilk "UART"文字(X42.9、コネクタの右隣印字)に合わせて開口を作ったため
    約7mm右にズレていた。開口を X33.4-43.5(Micro-USBにセンタリング)へ修正。
    ボード重ねレンダで中央に収まることを確認。connector_mapの誤記(MIPI DSI)も訂正。
    [case_base.3mf, case_base.stl, rdk_x5_case.scad]
2026-06-24 5プレート版3mfをv5.2に更新・baseプレビュー画像を刷新
    - rdk_x5_case.3mf: ユーザーがBambu Studioでv5.2ジオメトリ(UART位置修正済)で
    5プレート再作成。base前壁の開口がUSB-C×2+UARTで密に並ぶ=v5.2であることを
    メッシュ抽出+正面レンダで確認済
    - images/case_base.png: 旧版(四隅ポストのある古い設計・UART穴なし)を、現行
    v5.2の外観(前壁USB-C×2+UART開口が見える3/4ビュー)に差し替え
    [rdk_x5_case.3mf]
2026-06-24 ヒーロー画像を追加(ボード入り/蓋フロート)
    実機RDK X5メッシュを重ねた「シズル感」レンダを追加:
    - hero_board_in_case: ボードがベースに収まり全ポート整合
    - hero_closed_exploded / hero_fan_exploded: 蓋がパチっと乗る分解ビュー
    READMEトップを刷新(SHOW=20-23 ヒーローモードを追加)
2026-06-24 scad同期: SHOW=20-23 ヒーローレンダモード
    [rdk_x5_case.scad]
2026-06-25 README: ファン蓋の推奨ハード(4010 + M3×15mm)と組立実測41℃を追記
    実機で確認: 4010ファン + M3×15mmネジがファン蓋にぴったり。
    密閉組立での冷却を 66℃→41℃(-25℃)に更新。
2026-11-03 v5.3: fix board not fitting (ledge relief, wider gap, bead clipped at connectors)
    Checked against the official STEP model:
    - Parts hang up to 1.9 mm below the PCB along the front edge at X 42-59
    (CSI connector area) and sat on the perimeter ledge, so the board never
    reached the floor. Cut the ledge away over X 40.5-60.5.
    - Front USB-C/UART stick out 1.28 mm and left HDMI 2.3 mm past the PCB
    edge, but the gap was 1.0 mm and only 0.45 mm at the snap ridge.
    GAP 1.00 -> 1.30, LEDGE 2.0 -> 2.6, and no snap ridge over the front
    connector span and the left HDMI/audio span.
    - Seated board now has zero interference with the base.
    - Regenerated the five STLs. The 3MF files are not regenerate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
2026-11-03 v5.3: regenerate 3MF files and preview images
    - Single-part 3MFs re-exported from the v5.3 SCAD.
    - Bambu Studio 5-plate project: meshes swapped for the v5.3 parts,
    plates, transforms and print settings kept, plate thumbnails redrawn.
    - All README / MakerWorld preview images re-rendered (board overlay
    uses the mesh converted from the official STEP; not committed).
    Claude-Session: https://claude.ai/code/session_011EsR3oXyvSpEMmeMTkq9Zy
2026-11-03 README: update for v5.3 (insertion steps, parameters, footprint, changelog)
    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
2026-11-04 README: v5.3 test print confirmed the board fits
    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
